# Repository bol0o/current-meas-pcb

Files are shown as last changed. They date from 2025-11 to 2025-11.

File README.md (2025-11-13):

# Current measurement PCB
### AGH Space Systems entry project

*Project was built using KiCad*

This PCB is used to measure current up to 50 amps on high-side (with at least .35mm of solder applied on power traces / **10 amps max without it**).
Voltage should be between 2.7V and 60V.

Analog output of the board is between 0 and 3.25V @ 50amp (with max voltage being clamped to applied VCC).

M2.5 mounting holes are present (36.325mm x 29.500mm center to center)

## Recommended components

| Component nr. | LCSC part nr. | Package |
| --- | --- | --- |
| U1 | C44322 | SOT-23-5 |
| R1 | C469426 | 2512 |
| R2 | C2933305 | 0805 |
| R3 | C17414 | 0805 |
| C1 | C49678 | 0805 |
| C2 | C53134 | 0805 |
| J1 | C475108 | Through Hole,P=10.16mm |
| J2 | C2937625 | Through Hole,P=2.54mm  |
| D1 | C42445803 | SOD-123 |

## Images

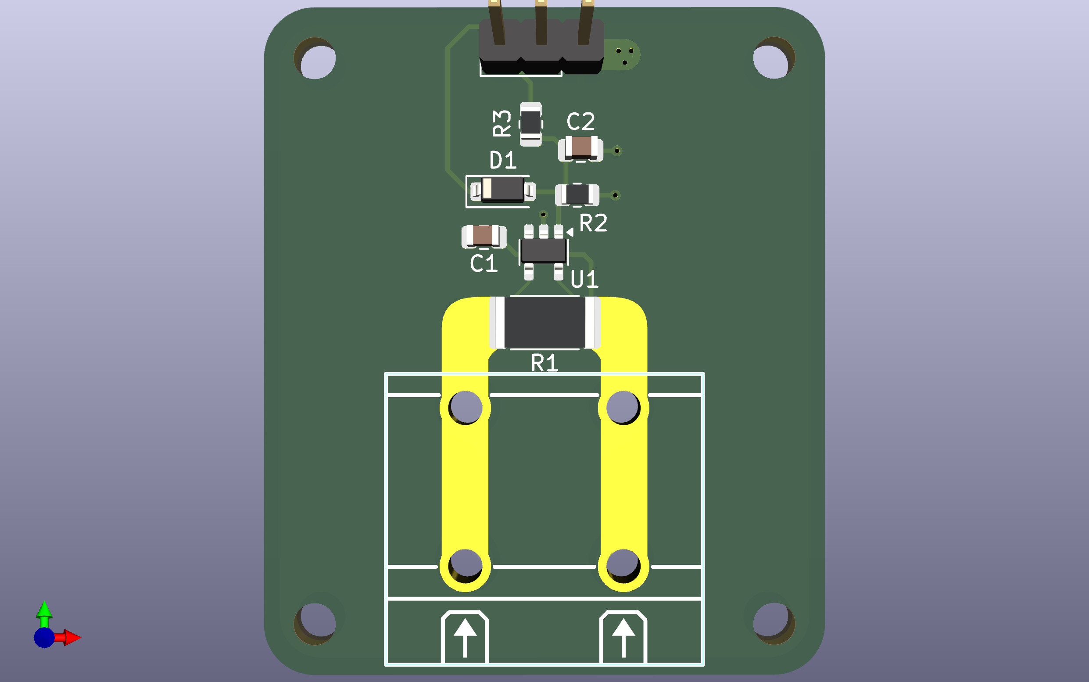
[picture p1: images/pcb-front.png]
pcb front


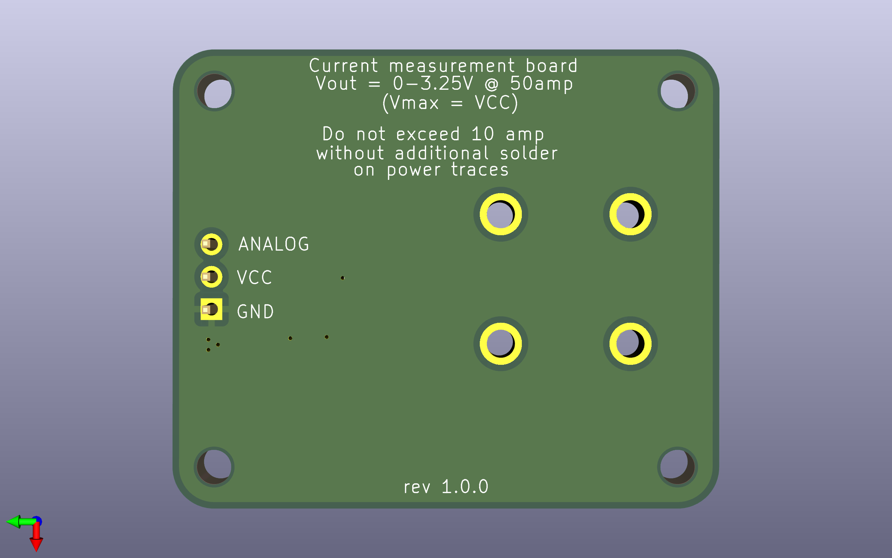
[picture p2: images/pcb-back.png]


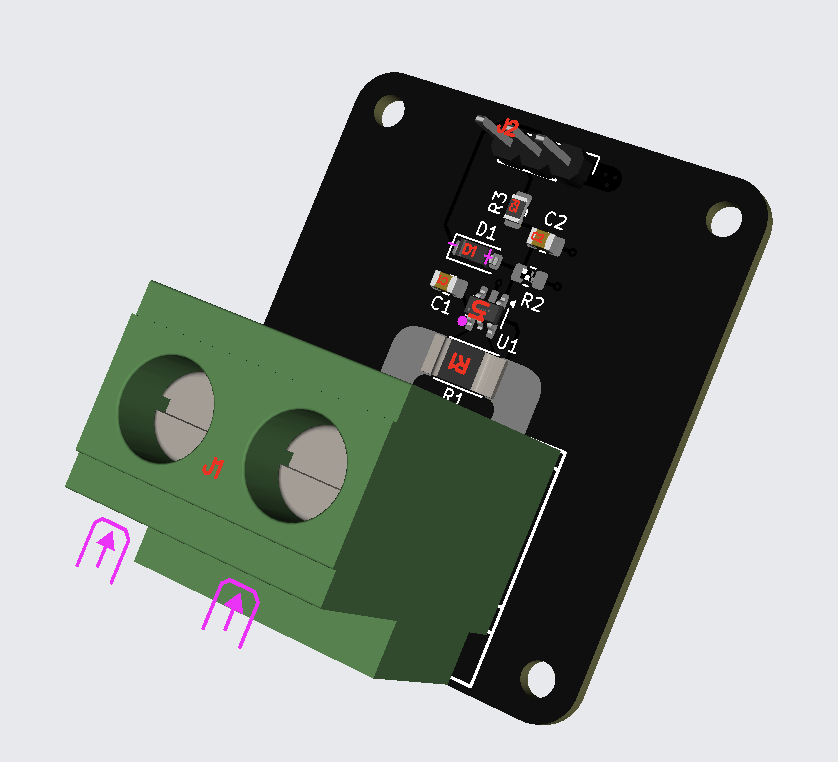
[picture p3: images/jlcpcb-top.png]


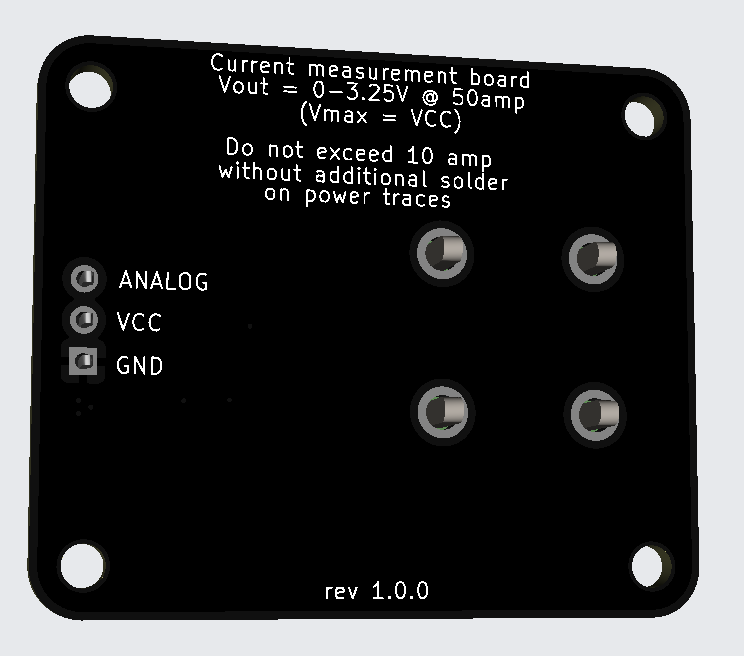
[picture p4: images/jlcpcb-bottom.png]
pcb bottom


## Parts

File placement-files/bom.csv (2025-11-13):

Reference | Qty | Value | DNP | Exclude from BOM | Exclude from Board | Footprint | Datasheet
C1 | 1 | 100n |  |  |  | Capacitor_SMD:C_0805_2012Metric | ~
C2 | 1 | 47n |  |  |  | Capacitor_SMD:C_0805_2012Metric | ~
D1 | 1 | D_Schottky |  |  |  | Diode_SMD:D_SOD-123 | ~
H1,H2,H3,H4 | 4 | MountingHole |  | Excluded from BOM |  | MountingHole:MountingHole_2.7mm_M2.5 | ~
J1 | 1 | Screw_Terminal_01x02 |  |  |  | Custom:CONN-TH_P10.16_KF135T-10.16-2P | ~
J2 | 1 | Conn_01x03_Pin |  |  |  | Connector_PinHeader_2.54mm:PinHeader_1x03_P2.54mm_Vertical | ~
R1 | 1 | 0.5m |  |  |  | Resistor_SMD:R_2512_6332Metric | ~
R2 | 1 | 130k |  |  |  | Resistor_SMD:R_0805_2012Metric | ~
R3 | 1 | 220 |  |  |  | Resistor_SMD:R_0805_2012Metric | ~
U1 | 1 | INA169 |  |  |  | Package_TO_SOT_SMD:SOT-23-5 | http://www.ti.com/lit/ds/symlink/ina169.pdf

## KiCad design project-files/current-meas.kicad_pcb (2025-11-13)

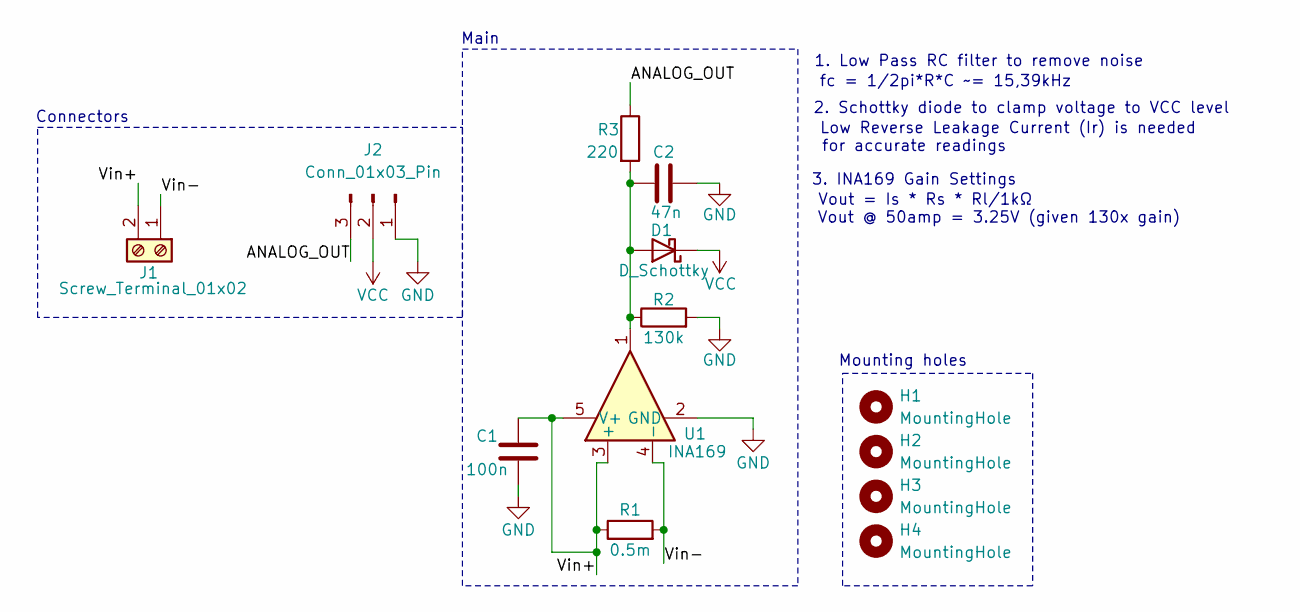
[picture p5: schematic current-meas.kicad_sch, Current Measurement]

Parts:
C1: 100n; C_0805_2012Metric
C2: 47n; C_0805_2012Metric
D1: D_Schottky; D_SOD-123
H1, H2, H3, H4: MountingHole; MountingHole_2.7mm_M2.5
J1: Screw_Terminal_01x02; CONN-TH_P10.16_KF135T-10.16-2P
J2: Conn_01x03_Pin; PinHeader_1x03_P2.54mm_Vertical
R1: 0.5m; R_2512_6332Metric
R2: 130k; R_0805_2012Metric
R3: 220; R_0805_2012Metric
U1: INA169; SOT-23-5

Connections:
/ANALOG_OUT: J2.3, R3.1
/Vin+: C1.1, J1.2, R1.1, U1.3 (+), U1.5 (V+)
/Vin-: J1.1, R1.2, U1.4 (-)
GND: C1.2, C2.2, J2.1, R2.2, U1.2 (GND)
unnamed: C2.1, D1.2 (A), R2.1, R3.2, U1.1
VCC: D1.1 (K), J2.2

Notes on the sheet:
Vout @ 50amp = 3.25V (given 130x gain)
Connectors
2. Schottky diode to clamp voltage to VCC level
Vout = Is * Rs * Rl/1kΩ
Main
for accurate readings
1. Low Pass RC filter to remove noise
3. INA169 Gain Settings
fc = 1/2pi*R*C ~= 15,39kHz
Mounting holes
Low Reverse Leakage Current (Ir) is needed

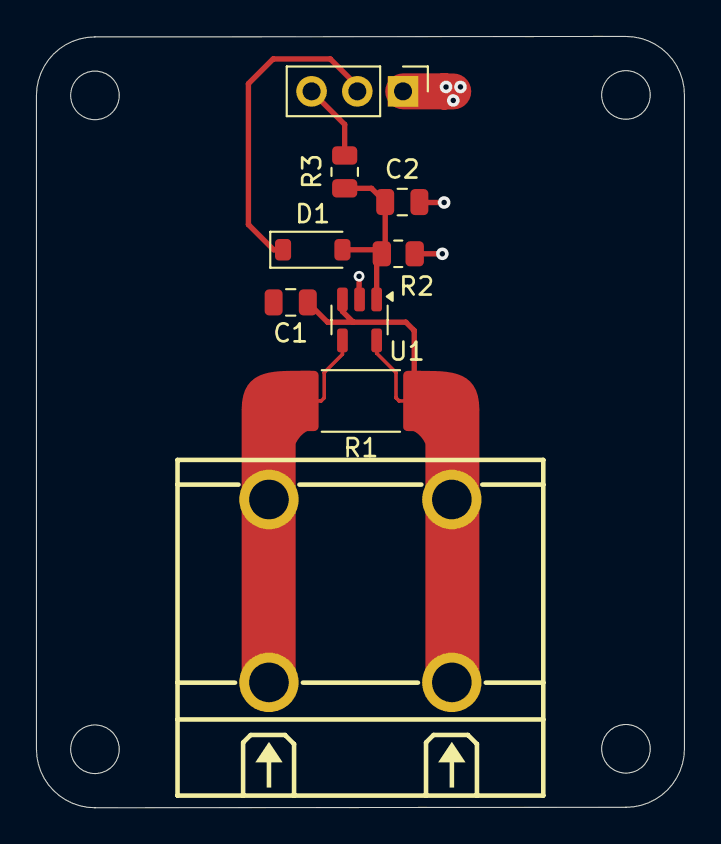
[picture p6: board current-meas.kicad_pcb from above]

Board: 2 copper layers, 36.0 x 42.8 mm, 13 parts (0 on the bottom side), 6 nets.
